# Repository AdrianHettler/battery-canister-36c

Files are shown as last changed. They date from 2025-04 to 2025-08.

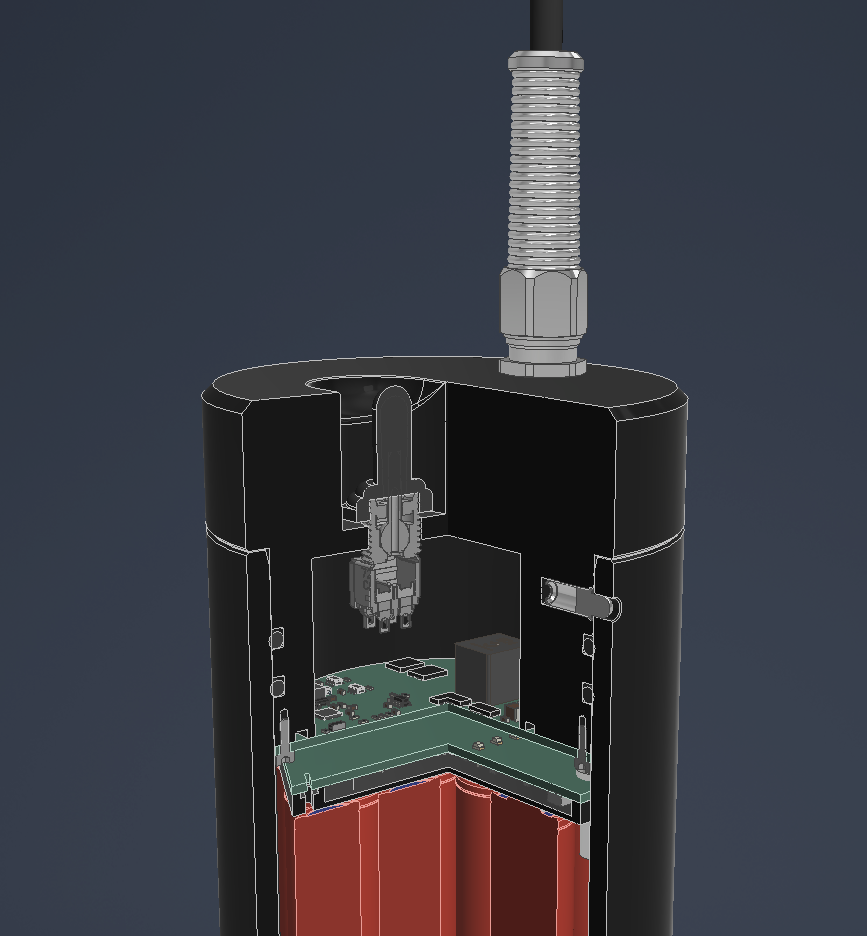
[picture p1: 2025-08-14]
mechanical/pictures/3.png

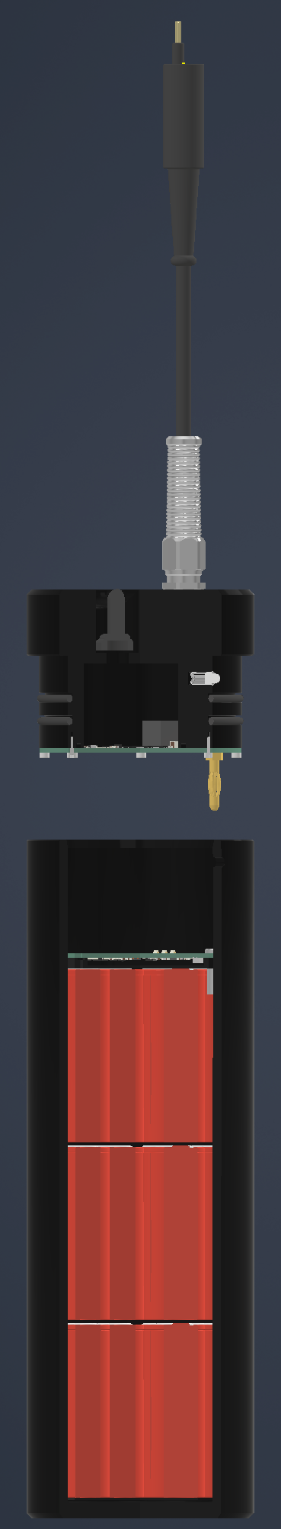
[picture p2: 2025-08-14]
mechanical/pictures/1.png

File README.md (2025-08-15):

# Design of a Battery Canister for Diving Purposes

> [!CAUTION]
> Improper use of Li-ion batteries, including short circuits or mishandling, can pose serious risks, potentially resulting in fires or explosions.
> 
<p align="center" width="100%">
     
</p>

<p align="center" width="100%">
     
</p>

# Design Guidelines and Requirements
The design guidelines and requirements are outlind in the following bullet points:
* Runtime BZ400h (115W): 3h -> Capacity: > 345Wh
* Max. power output of 180W
* Constant output voltage (Nominal 12V)
* Voltage boost to 13V
* PWM output control
* Use of toggle switches
* Option for single and dual output
* No exposed o-rings
* Compact design

# Mechanical
The lid and canister are sealed by two radial o-rings. A spring plunger locks the lid to the can. The boot of the toggle switch acts as a over pressure relieve device.

<p align="center" width="100%">
     
</p>

# Electrical
The main components of the electrical system consist of two printed circuit boards (PCBs) and the batteries. The first PCB (BMS Stage) is integrated into the battery pack and is used to monitor, protect and balance the pack. The second PCB (MCU & Buck Stage) steps down the battery pack voltage to a constant output voltage and monitors and controls the switches and output. The PCBs were designed in KiCad, hand assembled and reflow soldered in a modified toaster oven.

## Batteries
A total of 36 Sanyo NCR18650GS Li-ion batteries in a 6p6s arrangement are used. The pack provides a nominal voltage of 21.6V, a charge capacity of 20.7Ah and a energy capacity of 447.12Wh. The battery voltage is not a fixed value and depends on the state of charge of the cell. Hence, the pack voltage ranges from a minimum of 15V to a maximum of 25.2V. The single batteries are spot welded together with 0.2 x 6mm nickel strips. Three NTC therminstors are integrated into the pack to provide temperature readings to the BMS stage.

## BMS Stage
A Texas Instruments (TI) BQ40Z80 battery pack manager is used as primary protection for the battery pack. It has a full array of protection features (voltage, current, temperature, charge timeout, charge & discharge fets, AFE), uses gas gauging to determine and display the exact state of charge and is able to balance cells while charging or at rest. A TI BQ77207 battery protector serves as secondary protection in the event of failure of the primary system. The BQ77207 protects against over- and undervoltage and open-wire faults. A 30A SCF fuse (ITV9550) protects against over-current and short circuits. A resistive heating element inside of the fuse can be used to externally trigger the fuse in cause of a fault that requires permanent disabling of the battery pack. The BMS is designed to handle up to six cells in series. The PCB is mounted on top of the batterypack, a plastic spacer ensures isolation to the cells. 

<p align="center" width="100%">
     
</p>

Utilizing the EV2400 interface adapter and TI's Battery Management Studio (bqStudio) software, the BQ40Z80 IC can be programmed. After configuring the IC according to the used hardware, a learning cycle that determines the resistance and the total chemical capacity of the battery, needs to be performed.

## MCU & Buck Stage
A TI LM5146 synchronous buck DC/DC converter is used to step down the battery voltage to a constant value. A STM32L031 microcontroller is used for following tasks: 
* Check state of switch / button
* Switching of MOSFETs
* Monitoring of temperature of the pcb
* Monitoring of input voltage and stepped down output voltage
* Control of buzzer
* Enabling & disabling of buck converter
<p align="center" width="100%">
     
</p>

Due to the fact that the step down converter uses ~1-3W while idling without load, it is very important to be able to switch the buck converter off. This is done by connecting the second channel of the toggle switch in series with the converter's enable pin. If the switch is accidently put in the on-state, a different protection is used. The battery pack voltage drops when a load is applied. A monitoring routine is therefore implemented that sporadically switches the power MOSFETs on and off and checks the battery pack voltages in these states. If a substential drop-of is detected, it is concluded that an acutal load is connected. Otherwise the buck convertes is disabled by pulling the enable pin to ground with the help of a N-channel MOSFET. The pcb can support dual input / output. The step down converter is optimized to reach higher efficiencies with increasing loads.

### Performance of Buck Converter

Due to conduction, switching and inductor losses, the buck converter does not run at 100% efficiency. The diagramms below show the efficiency and power losses at different input voltages (battery voltage) and under different loads. 

<p align="center" width="100%">
     
</p>

<p align="center" width="100%">
     
</p>

# Assembly
Following are some pictures of the assembly process

<p align="center" width="100%">
     
</p>
<p align="center" width="100%">
     
</p>
<p align="center" width="100%">
     
</p>
<p align="center" width="100%">
     
</p>

<p align="center" width="100%">
     
</p>
<p align="center" width="100%">
     
</p>
<p align="center" width="100%">
     
</p>

# Testing
To test the watertightness of the cannister, it is set into a home build preassure chamber, filled with water and pressurized to 8bar. After two hours, the inside of the canister is checked for leaks.
<p align="center" width="100%">
     
</p>

# Lessons Learned
* Delrin from China can be porous
* Double and tripple check schematics
* It might be easier to select o-rings from the actual dimension of the manufactured part

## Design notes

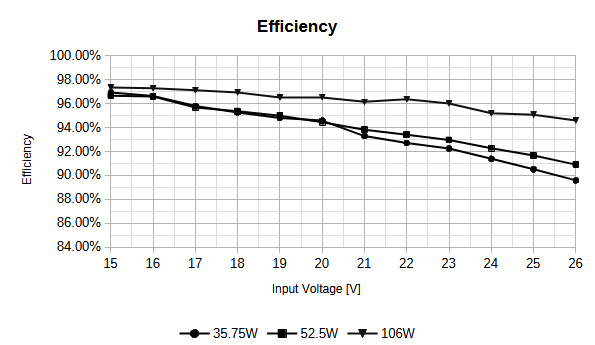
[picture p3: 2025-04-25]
electrical/buck_mcu_stage/efficiency.png

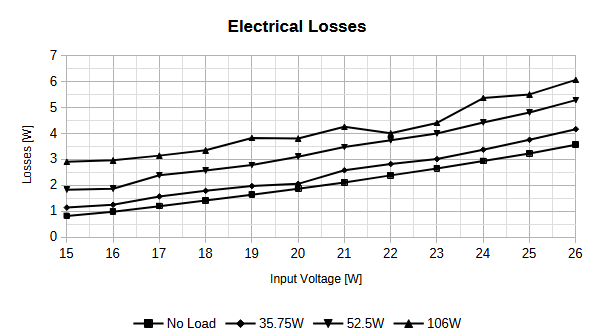
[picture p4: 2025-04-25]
electrical/buck_mcu_stage/losses.png

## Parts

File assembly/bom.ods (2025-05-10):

Part | Part No. | Manufacturer | Quantity | Price / Pcs. | Total Price | Comment | Link
Lid |  |  | 1 | 98.90 € | 98.90 € |  | https://www.pcbway.com/rapid-prototyping/manufacture/
Cannister |  |  | 1 | 184.80 € | 184.80 € |  | https://www.pcbway.com/rapid-prototyping/manufacture/
WAM Cord | DZ23025 | DIRZONE | 1 | 69.00 € | 69.00 € |  | https://www.uwfun24.de/WAM-cord-schwarz-120cm
Cable Gland | 1060.12.52.065 | KAISER GmbH & Co. KG | 1 | 24.00 € | 24.00 € | Can be purchased in pack of 10 for ~10€ each | https://www.uwfun24.de/WAM-E-O-Cord-Verschraubung-mit-Knickschutz
Switch Boot | YD-Switch Cap | Yellow Diving | 1 | 16.90 € | 16.90 € |  | https://www.tauchservice.info/en/yellow-diving/yellow-diving-switch-cap/YD-Switch-Cap.html
Switch | 2BL62-73 | Carling Technologies | 1 | 11.54 € | 11.54 € |  | https://eu.mouser.com/ProductDetail/Carling-Technologies/2BL62-73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
O-Ring | 196-5070 | RS Components | 2 | 1.00 € | 2.00 € | 8.77€ / 20pcs | https://de.rs-online.com/web/p/dichtungen-und-o-ringe/1965070
Spring Plunger | 03077-05 | Norelem | 1 | 2.05 € | 2.05 € |  | https://norelem.de/en/Product-overview/Flexible-standard-component-system/03000/Spring-plungers/Spring-plungers-smooth-version/p/agid.20025
Batteries | NCR18650GA | Sanyo | 36 | 3.78 € | 136.08 € |  | https://www.nkon.nl/de/sanyo-18650ga.html
Electronic Components |  |  | 1 | 70.00 € | 70.00 € | Approximation (Check pcb boms) | https://www.mouser.de/
Temperature Sensors | NTCLE305 | Vishay | 3 | 1.69 € | 5.07 € |  | https://de.rs-online.com/web/p/thermistoren/1793884
PCBs |  | JLCPCB | 1 | 40.00 € | 40.00 € |  | https://jlcpcb.com/
 |  |  |  | Total: | 660.34 €

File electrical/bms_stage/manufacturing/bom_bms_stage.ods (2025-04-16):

Reference | Value | Footprint | Qty
C1,C2,C3,C4,C5,C6,C7,C8,C9,C10,C11,C12,C13,C14,C15,C17,C18,C19,C21,C22,C23,C24,C25,C26 | 100n | C0603 | 24
C16 | 100p | C0603 | 1
C20 | 2u2 | C0603 | 1
D1,D2,D3,D4,D9 | BAT54H |  | 5
D5,D8 | TPD1E10B06 |  | 2
D14 | 1.5SMBJ30A |  | 1
F1 | ITV9550L3030MR |  | 1
LED1 | APT2012SURCK |  | 1
LED2 | APT2012SECK |  | 1
LED3 | APT2012SYCK |  | 1
LED4,LED5,LED6 | APT2012SGC |  | 3
Q1,Q2,Q3,Q4,Q5 | Si2302CDS |  | 5
Q6 | Si2301CDS |  | 1
Q7 | DMN6075S |  | 1
Q8,Q10 | CSD17573 |  | 2
Q9 | Si2347DS |  | 1
Q11 | 2N7002K |  | 1
Q12 | MMBT2907ALT1G |  | 1
R1,R2,R3,R4,R5,R6,R36,R40 | 1k | R0603 | 8
R7,R27,R28,R29,R32,R39 | 5k1 | R0603 | 6
R8,R9,R10,R11,R12,R13 | 42R / 500mW | R1210 | 6
R14,R15,R16,R17,R18,R19,R21,R22,R25,R31,R33,R34,R38 | 100R | R0603 | 13
R20 | 20k | R0603 | 1
R23,R30,R35 | 10M | R0603 | 3
R24 | 1mR / 2W | R2512 | 1
R26 | 1k / 0,5W | R0805 | 1
R37 | 10k | R0603 | 1
SW1 | 431181015816 |  | 1
U1 | BQ7720700 |  | 1
U2 | BQ40Z80 |  | 1

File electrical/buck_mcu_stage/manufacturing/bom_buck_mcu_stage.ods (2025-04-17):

Reference | Value | Footprint | Qty
BZ1 | CMT5023SSMTTR |  | 1
C1,C2,C3,C8,C9,C11,C13,C14,C15,C16,C17,C18 | 100n | C0603 | 12
C4,C5 | 4u7 | C1210 | 2
C6 | 56n | C0603 | 1
C7,C25 | 2u2 | C0603 | 2
C10 | 1u | C0603 | 1
C12 | 12p | C0603 | 1
C19 | 8n2 | C0603 | 1
C20 | 680p | C0603 | 1
C21 | 560p | C0603 | 1
C22,C23,C24 | 22u | C1210 | 3
D1 | BAT54H |  | 1
L1 | MMZ1608R601ATD25 | L0603 | 1
L2 | XAL1010-332MED |  | 1
Q1,Q2,Q7 | BSS138 |  | 3
Q3 | CSD18540Q5B |  | 1
Q4 | CSD18510Q5B |  | 1
Q5,Q6 | CSD17573Q5B |  | 2
R1,R4,R6 | 75k | C0603 | 3
R2,R9,R17,R18,R19,R20 | 36R | C0603 | 6
R3,R10,R11 | 20k | C0603 | 3
R5 | 10K | C0603 | 1
R7,R26 | 8k25 | C0603 | 2
R8 | 39k2 | C0603 | 1
R12 | 2R2 | C0603 | 1
R13 | 475R | C0603 | 1
R14 | 1k91 | C0603 | 1
R15 | 18k | C0603 | 1
R16 | 1k27 | C0603 | 1
R21 | 26k1 | C0603 | 1
R22,R23,R24,R25 | 100k | C0603 | 4
U1 | TPS7B92033DBVR |  | 1
U2 | LM5146RGYR |  | 1
U4,U5 | UCC27517AQDBVRQ1 |  | 2
U6 | STM32L031G6U6 |  | 1

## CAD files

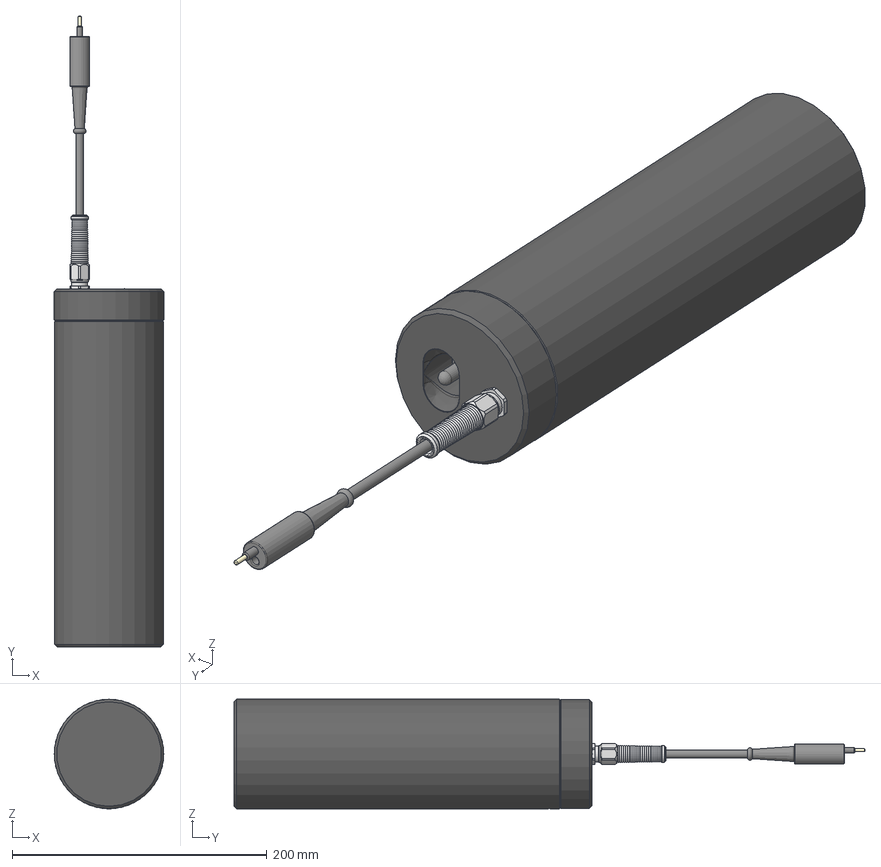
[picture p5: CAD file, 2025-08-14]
mechanical/cad/battery_canister_36cell_single_sw.stp
86.1 x 495.6 x 86.1 mm
cannister
18650-GA v2 x 36
bms_stage_bq40z80_
banana_jack x 2
pack_plate_bottom
pack_plate_top
lid
buck_mcu_stage
din_912-m2x0_4-6-8_8 x 8
wam_cord
yellow_boot
7201TCWZGE22
o_ring_70_3 x 2

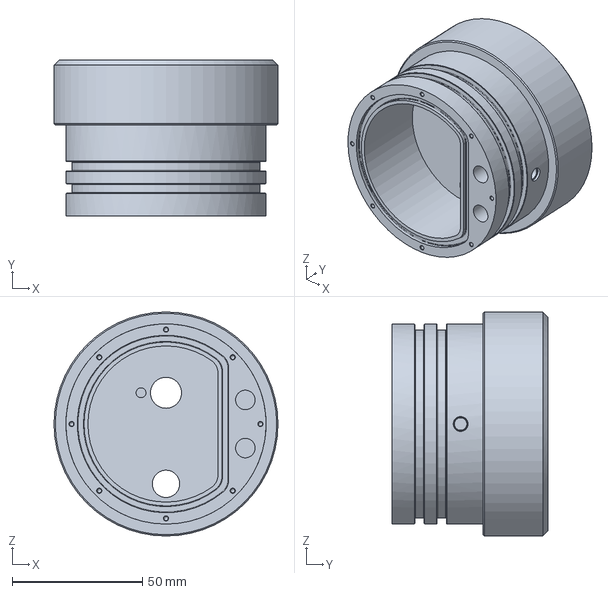
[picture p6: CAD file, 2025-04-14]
mechanical/manufacturing/lid.stp
86.1 x 60.0 x 86.1 mm

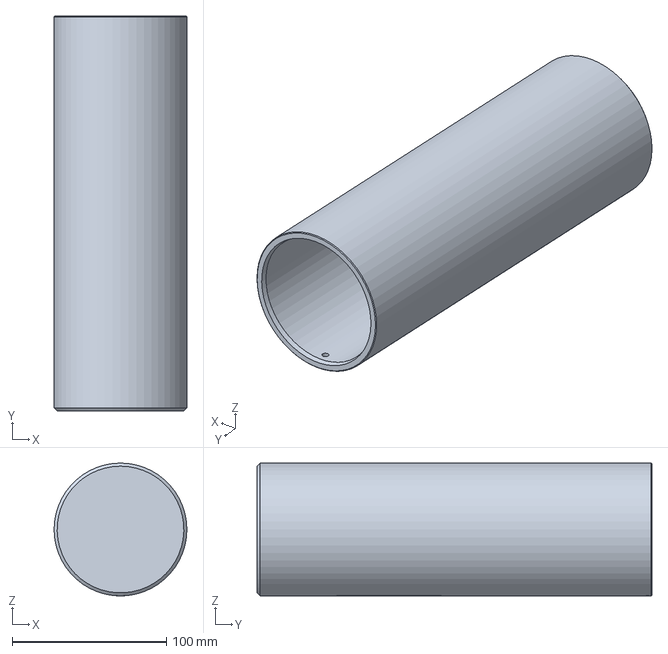
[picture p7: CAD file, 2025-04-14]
mechanical/manufacturing/cannister.stp
86.1 x 256.0 x 86.1 mm

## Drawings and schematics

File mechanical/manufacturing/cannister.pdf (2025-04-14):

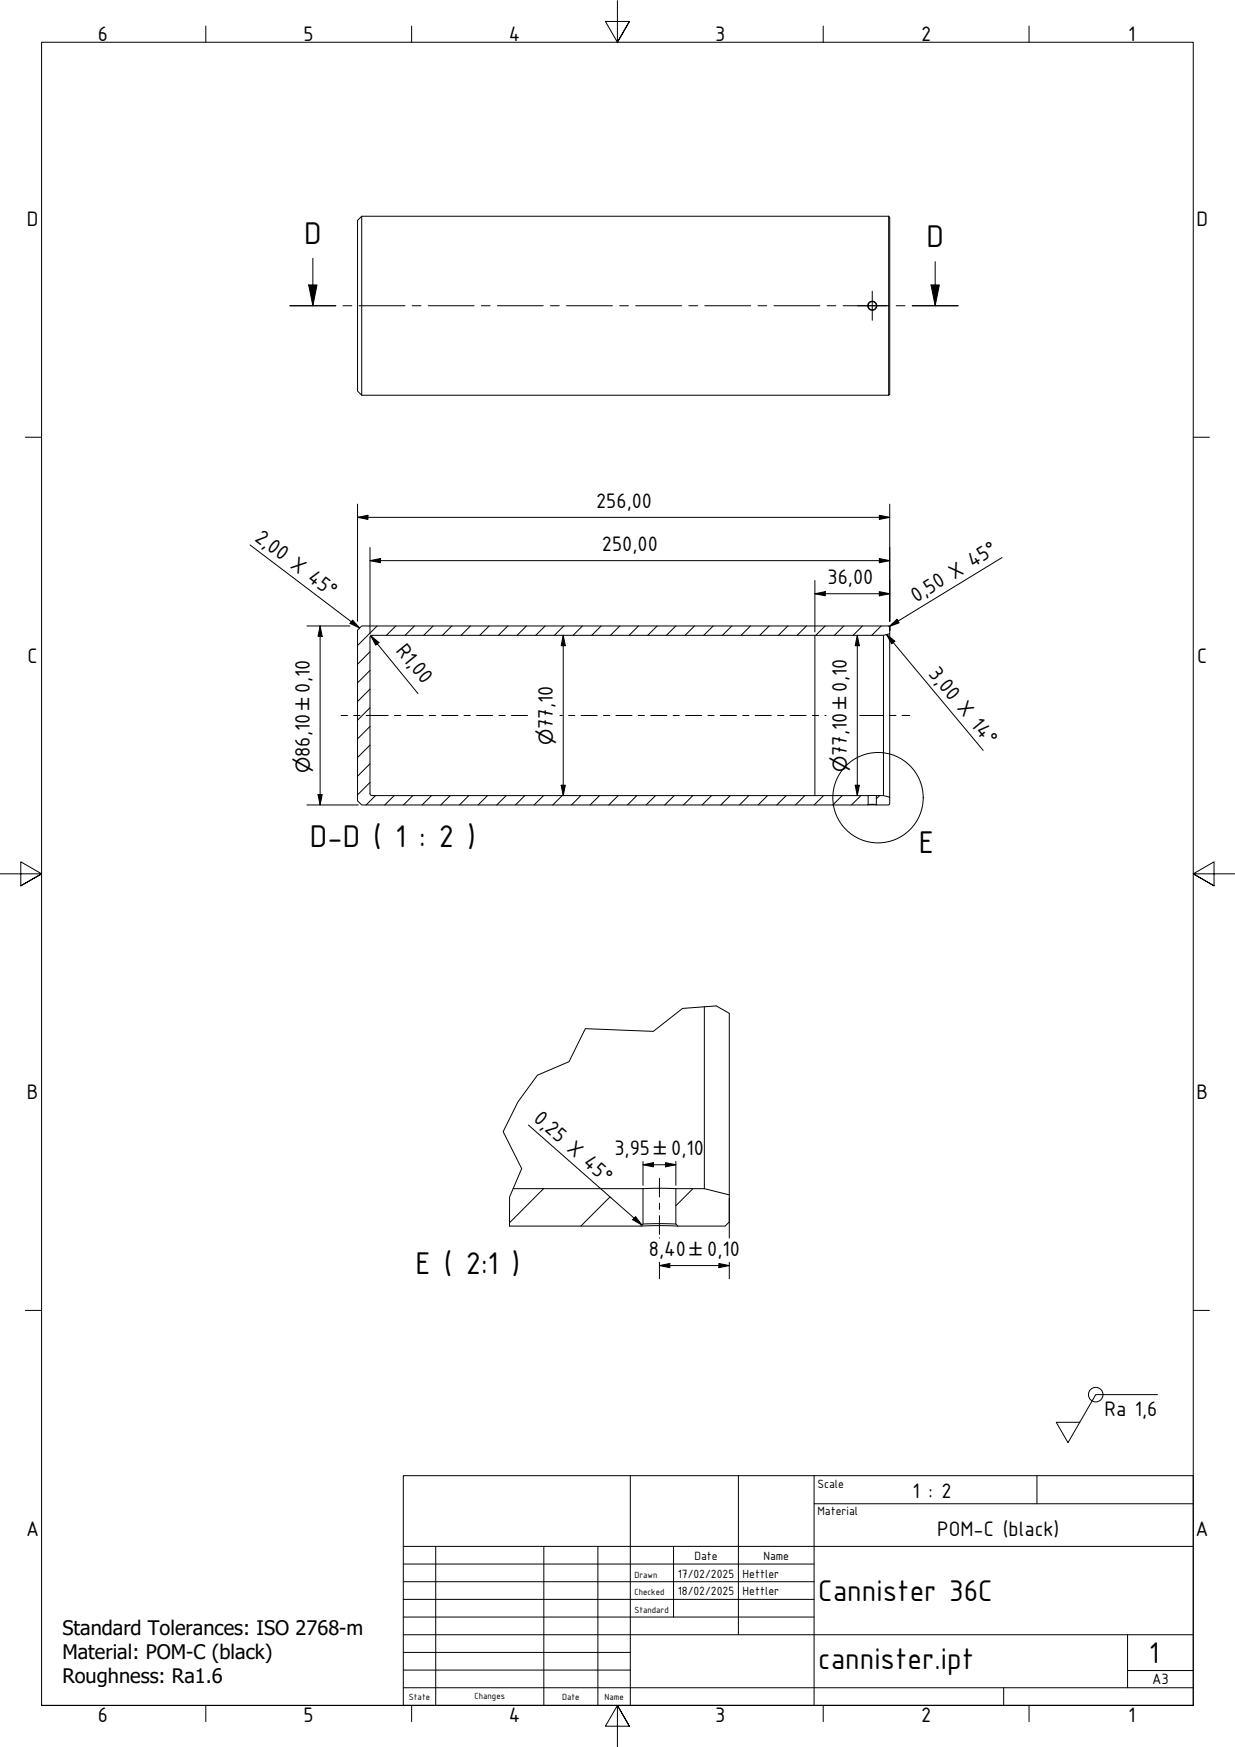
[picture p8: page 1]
POM-C (black)

Date | Name | Cannister 36C

Drawn | 17/02/2025 | Hettler

Checked | 18/02/2025 | Hettler

Standard

Standard Tolerances: ISO 2768-m
Material: POM-C (black)
Roughness: Ra1.6

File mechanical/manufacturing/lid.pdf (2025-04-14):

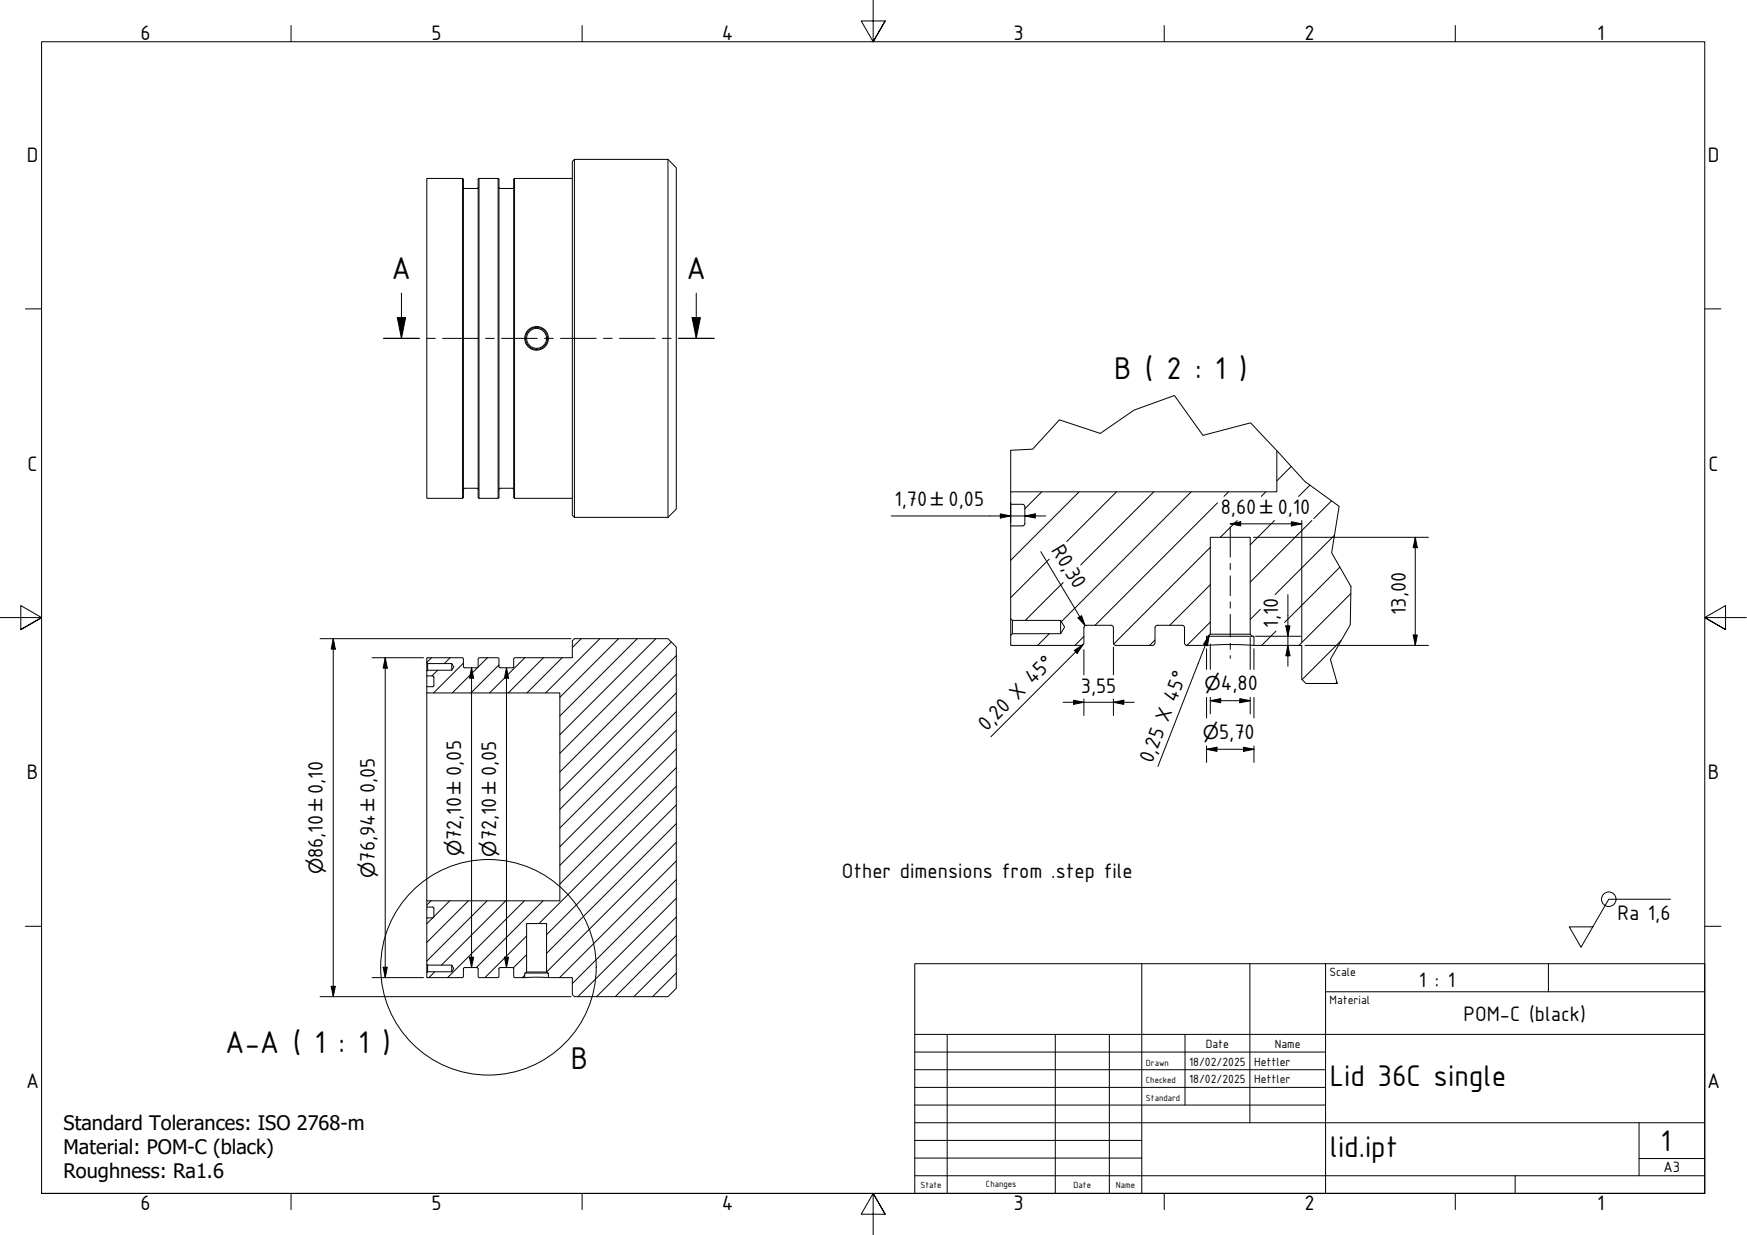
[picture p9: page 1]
POM-C (black)

Other dimensions from .step file

Date | Name | Lid 36C single

Drawn | 18/02/2025 | Hettler

Checked | 18/02/2025 | Hettler

Standard

Standard Tolerances: ISO 2768-m
Material: POM-C (black)
Roughness: Ra1.6

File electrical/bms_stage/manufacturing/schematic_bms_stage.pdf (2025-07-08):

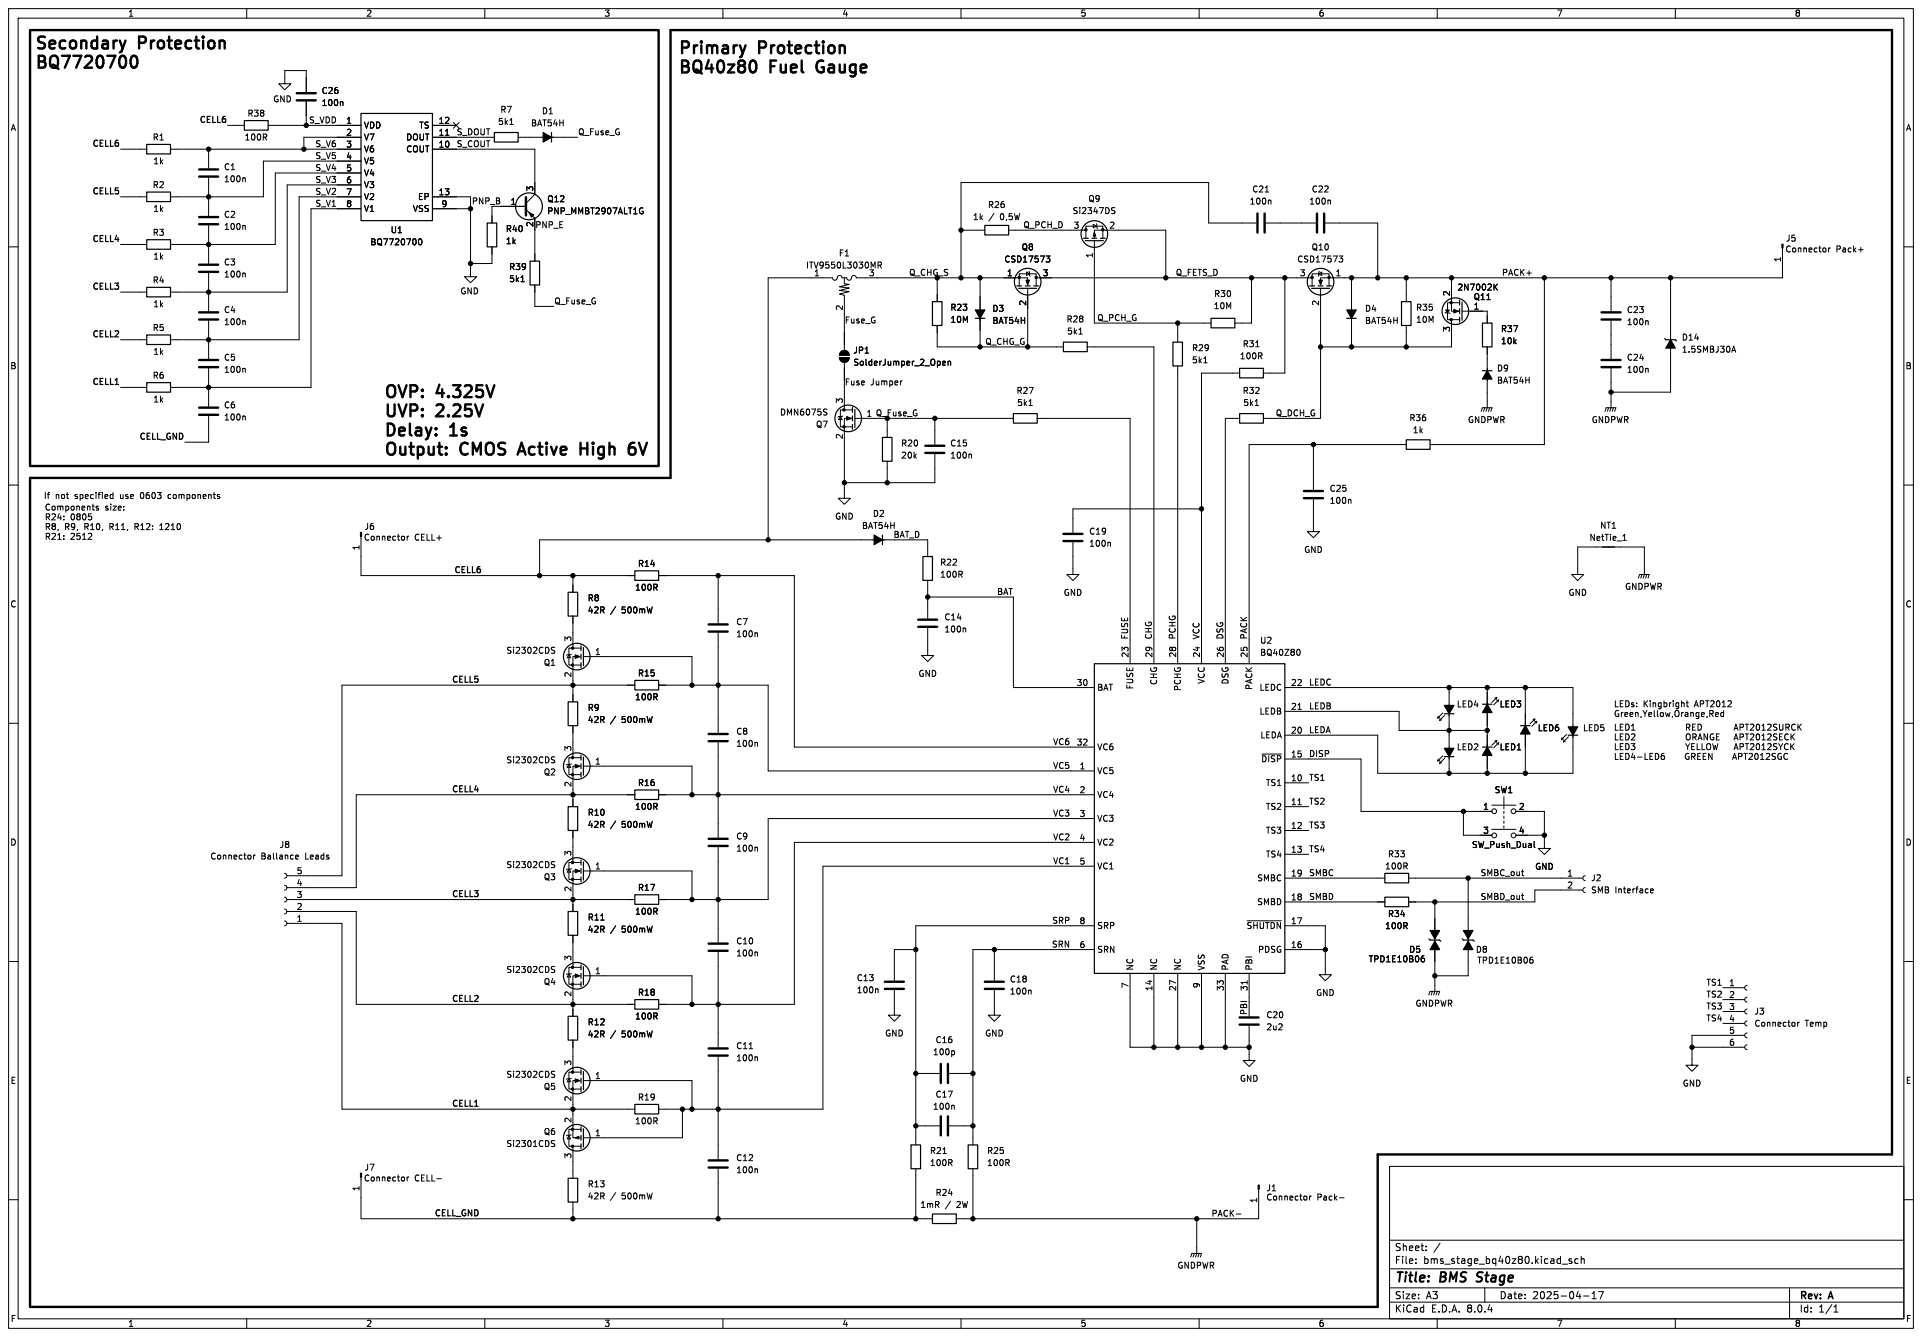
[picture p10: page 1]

~{DISP}15 PDSG 16 ~{SHUTDN}17 SMBD 18 SMBC 19 VC4 2

Id: 1/1 Title: BMS Stage

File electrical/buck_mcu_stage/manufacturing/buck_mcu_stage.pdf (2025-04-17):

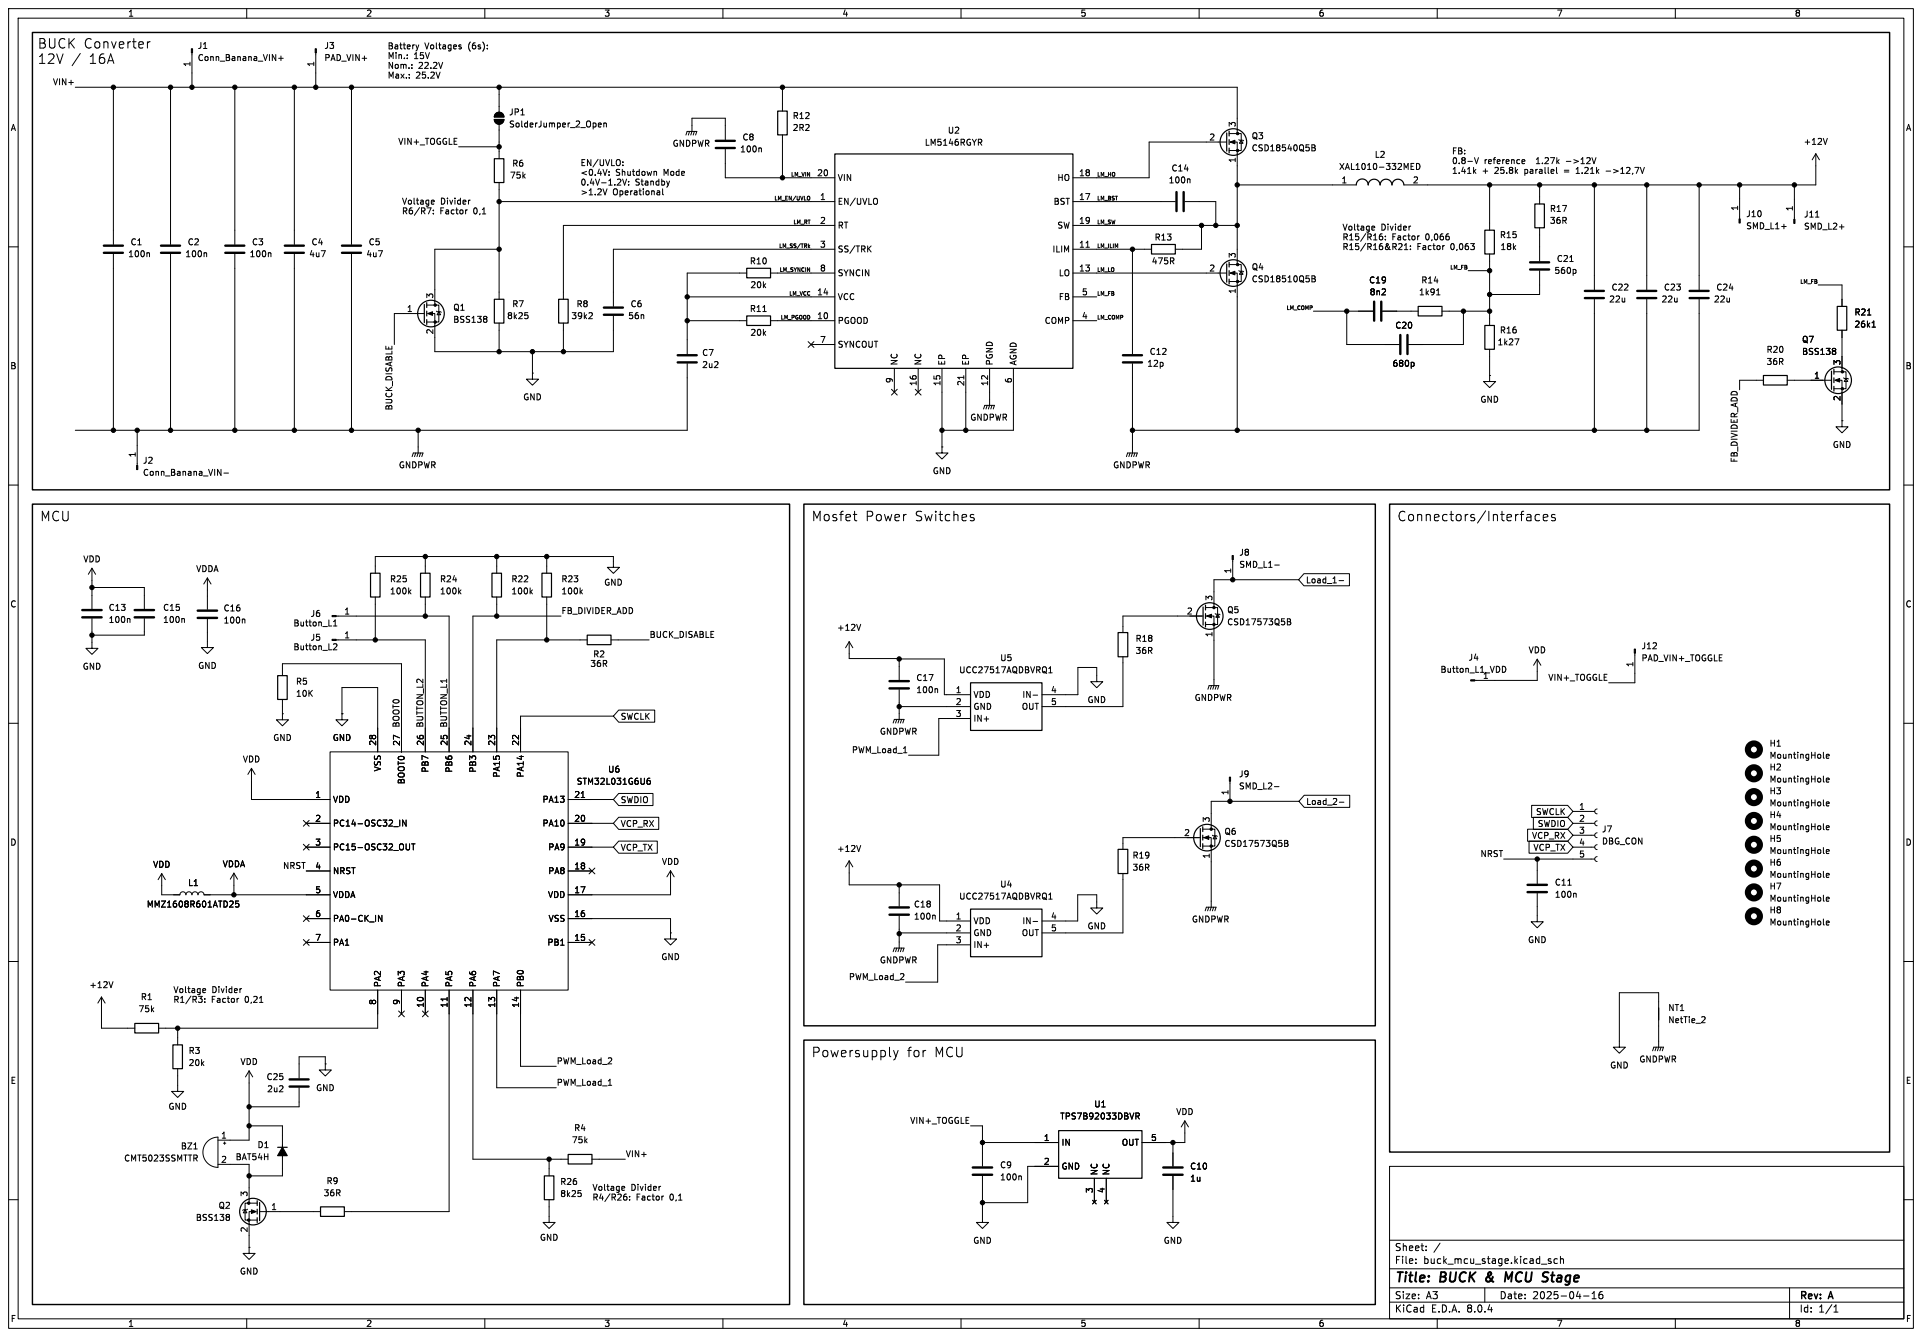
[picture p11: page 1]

EN/UVLO: <0.4V: Shutdown Mode

Battery Voltages (6s): Min.: 15V Nom.: 22.2V Max.: 25.2V MCU

H6 MountingHole H4 MountingHole H7 MountingHole H5 MountingHole R23

Id: 1/1 Title: BUCK & MCU Stage

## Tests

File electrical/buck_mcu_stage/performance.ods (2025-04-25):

VOUT | 12.14 | V
VIN | 15 | 16 | 17 | 18 | 19 | 20 | 21 | 22 | 23 | 24 | 25 | 26
no load [A] | 0.054 | 0.061 | 0.07 | 0.078 | 0.086 | 0.093 | 0.1 | 0.108 | 0.115 | 0.122 | 0.129 | 0.137
No Load | 0.81 | 0.976 | 1.19 | 1.404 | 1.634 | 1.86 | 2.1 | 2.376 | 2.645 | 2.928 | 3.225 | 3.562
Loss [W] | 0.81 | 0.976 | 1.19 | 1.404 | 1.634 | 1.86 | 2.1 | 2.376 | 2.645 | 2.928 | 3.225 | 3.562
52.5W [A] | 3.635 | 3.41 | 3.24 | 3.07 | 2.92 | 2.79 | 2.675 | 2.565 | 2.465 | 2.38 | 2.3 | 2.23
52.5W | 54.525 | 54.56 | 55.08 | 55.26 | 55.48 | 55.8 | 56.175 | 56.43 | 56.695 | 57.12 | 57.5 | 57.98
Efficiency | 96.65% | 96.59% | 95.68% | 95.37% | 94.99% | 94.44% | 93.81% | 93.39% | 92.95% | 92.26% | 91.65% | 90.89%
Loss [W] | 1.825 | 1.86 | 2.38 | 2.56 | 2.77999999999999 | 3.09999999999999 | 3.47499999999999 | 3.73 | 3.99499999999999 | 4.42 | 4.79999999999999 | 5.27999999999999
8.73
105.9822
106W [A] | 7.26 | 6.81 | 6.42 | 6.075 | 5.78 | 5.49 | 5.25 | 5 | 4.8 | 4.64 | 4.46 | 4.31
106W | 108.9 | 108.96 | 109.14 | 109.35 | 109.82 | 109.8 | 110.25 | 110 | 110.4 | 111.36 | 111.5 | 112.06
Efficiency | 97.34% | 97.28% | 97.12% | 96.94% | 96.52% | 96.54% | 96.15% | 96.36% | 96.01% | 95.19% | 95.07% | 94.59%
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

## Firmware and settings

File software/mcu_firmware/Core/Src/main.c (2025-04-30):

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
/* Includes ------------------------------------------------------------------*/
#include "main.h"

ADC_HandleTypeDef hadc;
DMA_HandleTypeDef hdma_adc;

TIM_HandleTypeDef htim2;

UART_HandleTypeDef huart2;

/* USER CODE BEGIN PV */
uint32_t adc_buffer[3]; //[0]: v_out / [1]: v_in / [2]: temp
float v_out = 0;
float v_in = 0;
float temp = 0;

#define VOUT_MAX 13
#define VIN_MAX 30
#define TEMP_MAX 70
#define STOP_AFTER_H 4 //stop after 4h

/* USER CODE END PV */

void SystemClock_Config(void);
static void MX_GPIO_Init(void);
static void MX_DMA_Init(void);
static void MX_ADC_Init(void);
static void MX_TIM2_Init(void);
static void MX_USART2_UART_Init(void);
/* USER CODE BEGIN 0 */
float get_v_out()
 {
	return (((float) (adc_buffer[0] - 28) / 4095.f) * 3.3f* (75.0f + 20.0f)) / 20.0f;
 }

 float get_v_in()
 {
	 return (((float) (adc_buffer[1] - 25) / 4095.f) * 3.3f* (75.0f + 8.25f)) / 8.25f;
 }

 float get_temperature()
 {


	           temp = (((0.67f - 3.3f) * 1000.0) /1.61f) + 130.0f;

	           return temp;
	//float v_temp_inside = 3.3f*(float)adc_buffer[2]/4095.f;
	//return (1.f/((1.f/298.15f) + (1.f/3435.f) * log((v_temp_inside)/(3.3f-v_temp_inside))))-273.15f;
 }





/* USER CODE END 0 */

/**
  * @brief  The application entry point.
  * @retval int
  */
int main(void) {

	/* MCU Configuration--------------------------------------------------------*/

	/* Reset of all peripherals, Initializes the Flash interface and the Systick. */
	HAL_Init();

	/* Configure the system clock */
	SystemClock_Config();

	/* Initialize all configured peripherals */
	MX_GPIO_Init();
	MX_DMA_Init();
	MX_ADC_Init();
	MX_TIM2_Init();
	MX_USART2_UART_Init();

	/* USER CODE BEGIN 2 */
	/*#define ADC_VOUT_Pin GPIO_PIN_2
	 #define ADC_VOUT_GPIO_Port GPIOA
	 #define TIM_BUZZER_Pin GPIO_PIN_5
	 #define TIM_BUZZER_GPIO_Port GPIOA
	 #define ADC_VIN_Pin GPIO_PIN_6
	 #define ADC_VIN_GPIO_Port GPIOA
	 #define GPIO_LOAD1_Pin GPIO_PIN_7
	 #define GPIO_LOAD1_GPIO_Port GPIOA
	 #define GPIO_LOAD2_Pin GPIO_PIN_0
	 #define GPIO_LOAD2_GPIO_Port GPIOB
	 #define GPIO_BUCK_DISABLE_Pin GPIO_PIN_15
	 #define GPIO_BUCK_DISABLE_GPIO_Port GPIOA
	 #define GPIO_FB_DIVIDER_ADD_Pin GPIO_PIN_3
	 #define GPIO_FB_DIVIDER_ADD_GPIO_Port GPIOB
	 #define GPIO_BTN_L1_Pin GPIO_PIN_6
	 #define GPIO_BTN_L1_GPIO_Port GPIOB
	 #define GPIO_BTN_L2_Pin GPIO_PIN_7
	 #define GPIO_BTN_L2_GPIO_Port GPIOB*/

	HAL_ADC_Start_DMA(&hadc, adc_buffer, 3);
	HAL_TIM_PWM_Start(&htim2, TIM_CHANNEL_1);

	uint32_t start_time = HAL_GetTick(); //time in ms since startup
	uint32_t last_load_check = HAL_GetTick(); //time in ms since startup

	/* USER CODE END 2 */


	/* Infinite loop */
	/* USER CODE BEGIN WHILE */
	while (1) {
		float v_out = get_v_out();

		//check output voltage
		if (v_out > VOUT_MAX) {
			//HAL_GPIO_WritePin(GPIO_LOAD1_GPIO_Port, GPIO_LOAD1_Pin, GPIO_PIN_RESET);
			HAL_GPIO_WritePin(GPIO_LOAD2_GPIO_Port, GPIO_LOAD2_Pin,GPIO_PIN_RESET);
			HAL_Delay(1000);
			continue;
		}


		//manage max time running
		if((start_time + 3600 * 1000 * STOP_AFTER_H) < HAL_GetTick())
		{
			//disable buck converter
			HAL_GPIO_WritePin(GPIO_BUCK_DISABLE_GPIO_Port, GPIO_BUCK_DISABLE_Pin,GPIO_PIN_SET);

			//disable mosfets
			HAL_GPIO_WritePin(GPIO_LOAD2_GPIO_Port, GPIO_LOAD2_Pin,GPIO_PIN_RESET);
			//HAL_GPIO_WritePin(GPIO_LOAD2_GPIO_Port, GPIO_LOAD2_Pin,GPIO_PIN_RESET);
			HAL_Delay(1000);
			continue;
		}

		//routine to check if load is attached when turned on
		if(HAL_GPIO_ReadPin(GPIO_BTN_L2_GPIO_Port,GPIO_BTN_L2_Pin) && (last_load_check + 1000 * 15) < HAL_GetTick())
		{

			HAL_GPIO_WritePin(GPIO_BUCK_DISABLE_GPIO_Port, GPIO_BUCK_DISABLE_Pin,GPIO_PIN_RESET);

			HAL_Delay(100);

			float v_in_buck_enabled = get_v_in();

			HAL_GPIO_WritePin(GPIO_BUCK_DISABLE_GPIO_Port, GPIO_BUCK_DISABLE_Pin,GPIO_PIN_SET);

			HAL_Delay(100);

			float v_in_buck_disabled = get_v_in();

			if(v_in_buck_enabled < v_in_buck_disabled - 0.1f)
			{
				HAL_GPIO_WritePin(GPIO_BUCK_DISABLE_GPIO_Port, GPIO_BUCK_DISABLE_Pin,GPIO_PIN_RESET);
			}
			else
			{
			//	TIM2->ARR = (1000000UL / 300) - 1; // Set The PWM Frequency
			//	TIM2->CCR1 = 200; // Set Duty Cycle 50%
			//	HAL_Delay(100); // Wait For The Tone Duration
			//	TIM2->CCR1 = 0; // Set Duty Cycle 50%
			}

			last_load_check = HAL_GetTick();
		}

		//manage input
		if (HAL_GPIO_ReadPin(GPIO_BTN_L2_GPIO_Port,GPIO_BTN_L2_Pin) && v_out <= VOUT_MAX)
			HAL_GPIO_WritePin(GPIO_LOAD2_GPIO_Port, GPIO_LOAD2_Pin,GPIO_PIN_SET);
		else
			HAL_GPIO_WritePin(GPIO_LOAD2_GPIO_Port, GPIO_LOAD2_Pin,GPIO_PIN_RESET);





		HAL_Delay(50);

		/* USER CODE END WHILE */

		/* USER CODE BEGIN 3 */
	}
	/* USER CODE END 3 */
}

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


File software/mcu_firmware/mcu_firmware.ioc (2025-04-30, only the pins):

Mcu.UserName=STM32L031G6Ux
PA10.Signal=USART2_RX
PA13.Signal=SYS_SWDIO
PA14.Signal=SYS_SWCLK
PA15.GPIO_Label=GPIO_BUCK_DISABLE
PA15.Signal=GPIO_Output
PA2.GPIO_Label=ADC_VOUT
PA2.Signal=ADC_IN2
PA5.GPIO_Label=TIM_BUZZER
PA5.Signal=S_TIM2_CH1
PA6.GPIO_Label=ADC_VIN
PA6.Signal=ADC_IN6
PA7.GPIO_Label=GPIO_LOAD1
PA7.Signal=GPIO_Output
PA9.Signal=USART2_TX
PB0.GPIO_Label=GPIO_LOAD2
PB0.Signal=GPIO_Output
PB3.GPIO_Label=GPIO_FB_DIVIDER_ADD
PB3.Signal=GPIO_Output
PB6.GPIO_Label=GPIO_BTN_L1
PB6.Signal=GPIO_Input
PB7.GPIO_Label=GPIO_BTN_L2
PB7.Signal=GPIO_Input

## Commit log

2025-04-14 added cad manufacturing data
    [cannister.stp, lid.stp]
2025-04-16 added pcb manufacturing data
    [bms_stage_bq40z80-B_Mask.gbs, bms_stage_bq40z80-B_Paste.gbp, bms_stage_bq40z80-B_Silkscreen.gbo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]
2025-04-17 added firmware
    [bom_buck_mcu_stage.ods]
2025-04-25 added efficiency data
    [performance.ods]
2025-07-08 fixed led sequence
    [bms_stage_bq40z80-B_Mask.gbs, bms_stage_bq40z80-B_Paste.gbp, bms_stage_bq40z80-B_Silkscreen.gbo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]
2025-08-14 step + pics
    [battery_canister_36cell_single_sw.stp]

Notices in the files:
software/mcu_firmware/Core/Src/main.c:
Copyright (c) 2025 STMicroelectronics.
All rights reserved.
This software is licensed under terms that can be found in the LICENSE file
